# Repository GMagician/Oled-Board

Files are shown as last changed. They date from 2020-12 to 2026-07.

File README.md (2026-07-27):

>[!WARNING]
>The transfer of all repositories to my [Codeberg account](https://codeberg.org/GMagician) is currently ongoing. In the future, this project will be continued here!
# SDD1306 1.3" OLED Board

This board has been inspired by Leonerd it's an open source and open hardware.
On the hardware side is fully compatible (not tested with 5V input tolerant boards)
On software side there are some new features usefull for SMuFF device

**PLEASE NOTE REV1 HAS PCB ERRORS. TO PROPERLY WORK NEED SOME PCB, PINS, PADS AND ROUTES CUTTING. THESE SHOULD BE FIXED IN REV2 BRANCH**

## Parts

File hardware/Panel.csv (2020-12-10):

Id | Riferimento | Contenitore | Quantità | Valore | Produttore
1 | SW101 | RotaryEncoder_Alps_EC11E-Switch_Vertical_H20mm | 1 | Rotary Encoder + Switch
2 | U102 | SOP-20_7.5x12.8mm_P1.27mm | 1 | ATtiny4313
3 | J203 | OLED-128O064D | 1 | SSD1306
4 | R204 | R_0805_2012Metric_Pad1.20x1.40mm_HandSolder | 1 | 910K
5 | R203,R202,R201,R103,R102 | R_0805_2012Metric_Pad1.20x1.40mm_HandSolder | 5 | 4K7
6 | R105 | R_0805_2012Metric_Pad1.20x1.40mm_HandSolder | 1 | 180
7 | R104 | R_0805_2012Metric_Pad1.20x1.40mm_HandSolder | 1 | 330
8 | R101 | R_0805_2012Metric_Pad1.20x1.40mm_HandSolder | 1 | 560
9 | D201 | D_SOD-323 | 1 | 1N4148WS
10 | C207 | C_0805_2012Metric_Pad1.18x1.45mm_HandSolder | 1 | 10µF
11 | C206 | C_0805_2012Metric_Pad1.18x1.45mm_HandSolder | 1 | 2.2µF/16V
12 | C205,C104,C103,C102 | C_0805_2012Metric_Pad1.18x1.45mm_HandSolder | 4 | 0.1µF
13 | C204,C203,C202,C201,C101 | C_0805_2012Metric_Pad1.18x1.45mm_HandSolder | 5 | 1µF
14 | U101 | SOT-23 | 1 | XC6206P
15 | Q101 | SOT-23 | 1 | 2N7002
16 | J202 | PinHeader_1x02_P2.54mm_Vertical | 1 | Conn_01x02
17 | J201 | PinHeader_1x02_P2.54mm_Vertical | 1 | Power supply
18 | J104,J101 | PinSocket_1x02_P2.54mm_Vertical | 2 | Conn_01x02
19 | BZ101 | PUIAudio_SMT_0825_S_4_R | 1 | Buzzer
20 | SW104 | B3W-9000-RG2 | 1 | B3W-9000-RG2N
21 | SW103,SW102 | SW_SPST_Omron_B3FS-100xP | 2 | 10mm
22 | J103 | PinHeader_2x03_P2.54mm_Vertical | 1 | Header
23 | J102 | JST_XH_B6B-XH-A_1x06_P2.50mm_Vertical | 1 | Header

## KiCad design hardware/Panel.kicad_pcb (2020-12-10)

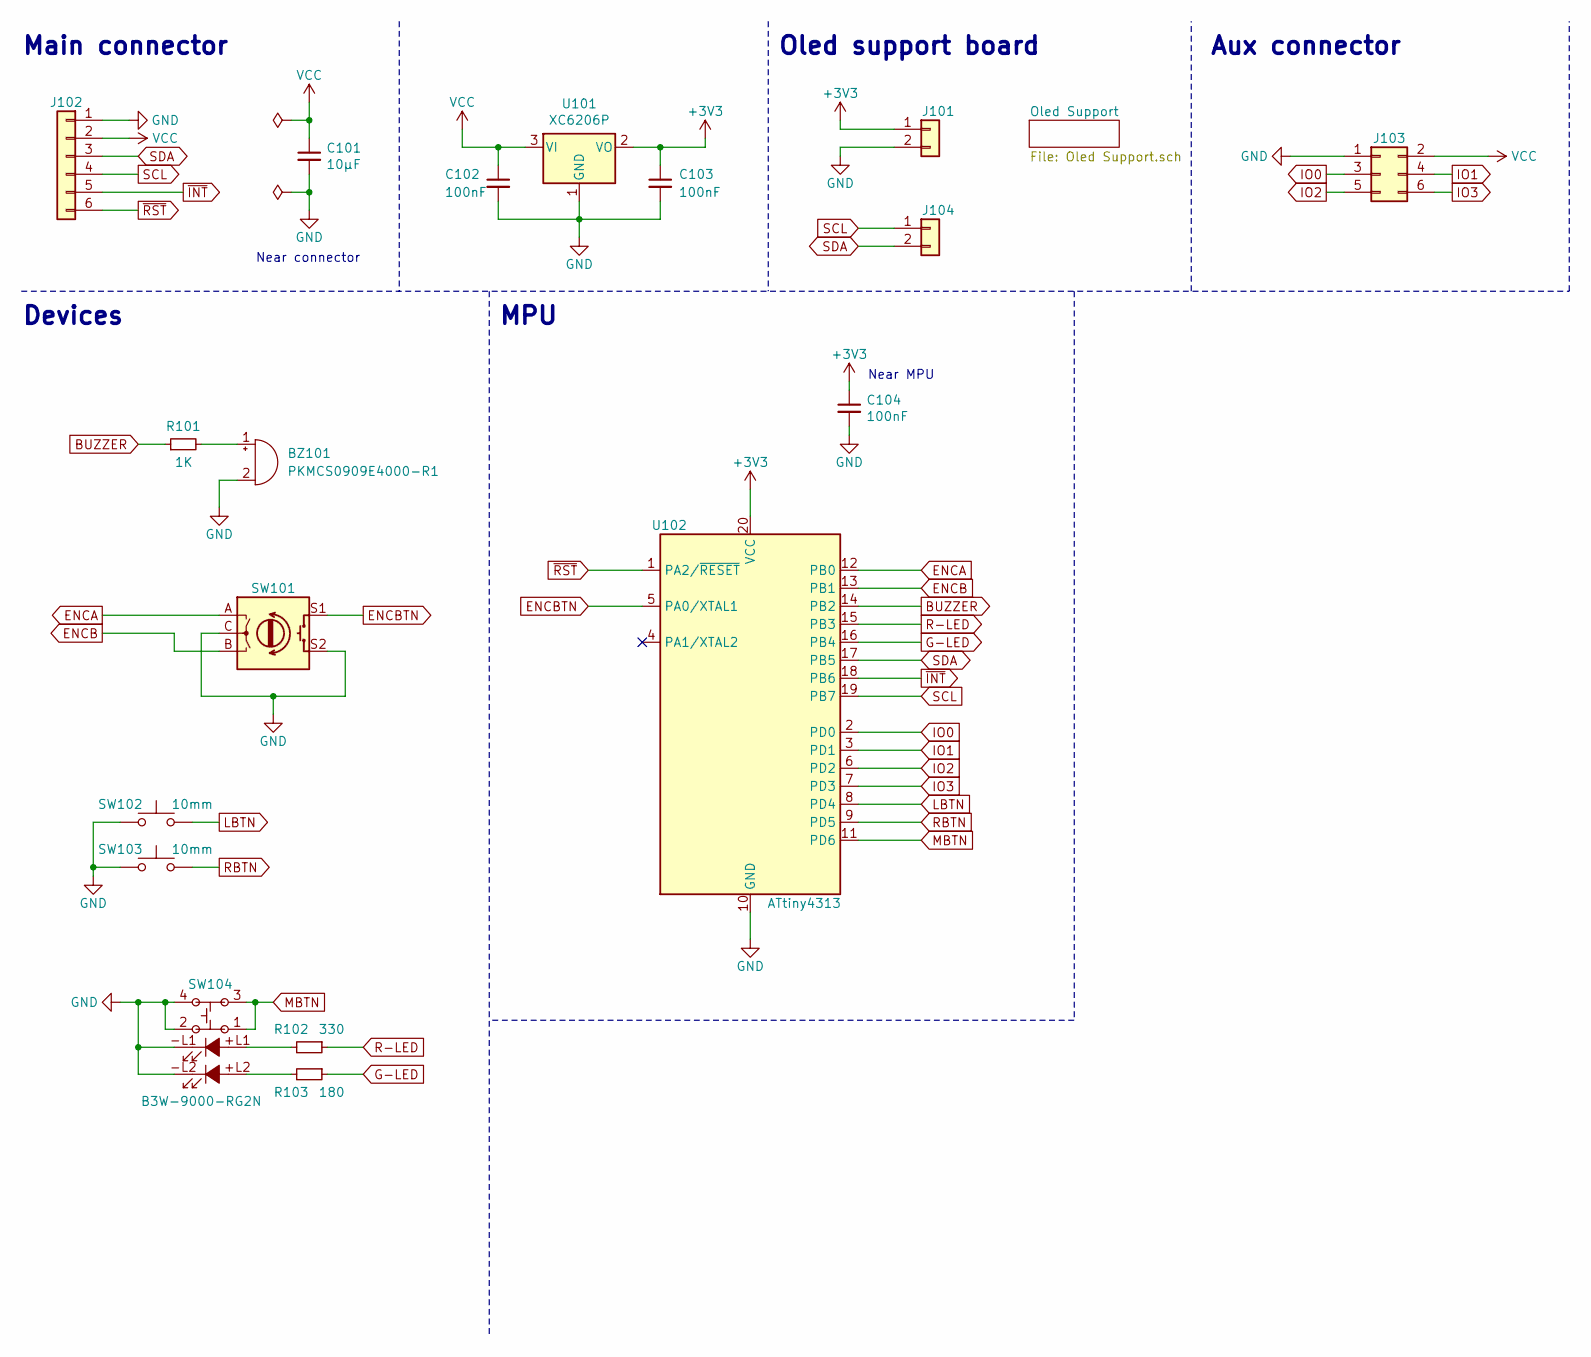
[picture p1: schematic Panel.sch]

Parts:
BZ101: PKMCS0909E4000-R1; Buzzer_Murata_PKMCS0909E4000-R1
C101: 10µF; C_0805_2012Metric_Pad1.18x1.45mm_HandSolder; LCSC C15850
C102, C103, C104: 100nF; C_0805_2012Metric_Pad1.18x1.45mm_HandSolder; LCSC C49678
J101, J104: Conn_01x02; OledSupport-header
J102: Header; JST_XH_B6B-XH-A_1x06_P2.50mm_Vertical
J103: Header; PinHeader_2x03_P2.54mm_Vertical
R101: 1K; R_0805_2012Metric_Pad1.20x1.40mm_HandSolder; LCSC C17513
R102: 330; R_0805_2012Metric_Pad1.20x1.40mm_HandSolder; LCSC C17630
R103: 180; R_0805_2012Metric_Pad1.20x1.40mm_HandSolder; LCSC C25270
SW101: Rotary Encoder + Switch; RotaryEncoder_Alps_EC11E-Switch_Vertical_H20mm
SW102, SW103: 10mm; SW_SPST_Omron_B3FS-100xP
SW104: B3W-9000-RG2N; B3W-9000-RG2
U101: XC6206P; SOT-23; LCSC C5446
U102: ATtiny4313; SOIC-20W_7.5x12.8mm_P1.27mm; LCSC C72467

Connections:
+3V3: C103.1, C104.1, J101.1, U101.2 (VO), U102.20 (VCC); also elsewhere on the board
BUZZER: R101.1, U102.14 (PB2)
ENCA: SW101.A, U102.12 (PB0)
ENCB: SW101.B, U102.13 (PB1)
ENCBTN: SW101.S1, U102.5 (PA0/XTAL1)
G-LED: R103.1, U102.16 (PB4)
GND: BZ101.2 (+), C101.2, C102.2, C103.2, C104.2, J101.2, J102.1, J103.1, SW101.C, SW101.S2, SW102.1, SW103.1, SW104.2, SW104.4, SW104.-L1, SW104.-L2, U101.1 (GND), U102.10 (GND); also elsewhere on the board
IO0: J103.3, U102.2 (PD0)
IO1: J103.4, U102.3 (PD1)
IO2: J103.5, U102.6 (PD2)
IO3: J103.6, U102.7 (PD3)
LBTN: SW102.2, U102.8 (PD4)
MBTN: SW104.1, SW104.3, U102.11 (PD6)
unnamed: BZ101.1 (-), R101.2
unnamed: R102.2, SW104.+L1
unnamed: R103.2, SW104.+L2
R-LED: R102.1, U102.15 (PB3)
RBTN: SW103.2, U102.9 (PD5)
SCL: J102.4, J104.1, U102.19 (PB7); also elsewhere on the board
SDA: J102.3, J104.2, U102.17 (PB5); also elsewhere on the board
VCC: C101.1, C102.1, J102.2, J103.2, U101.3 (VI)
~INT: J102.5, U102.18 (PB6)
~RST: J102.6, U102.1 (PA2/~RESET)

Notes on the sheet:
Main connector
Devices
Oled support board
Near connector
MPU
Near MPU
Aux connector

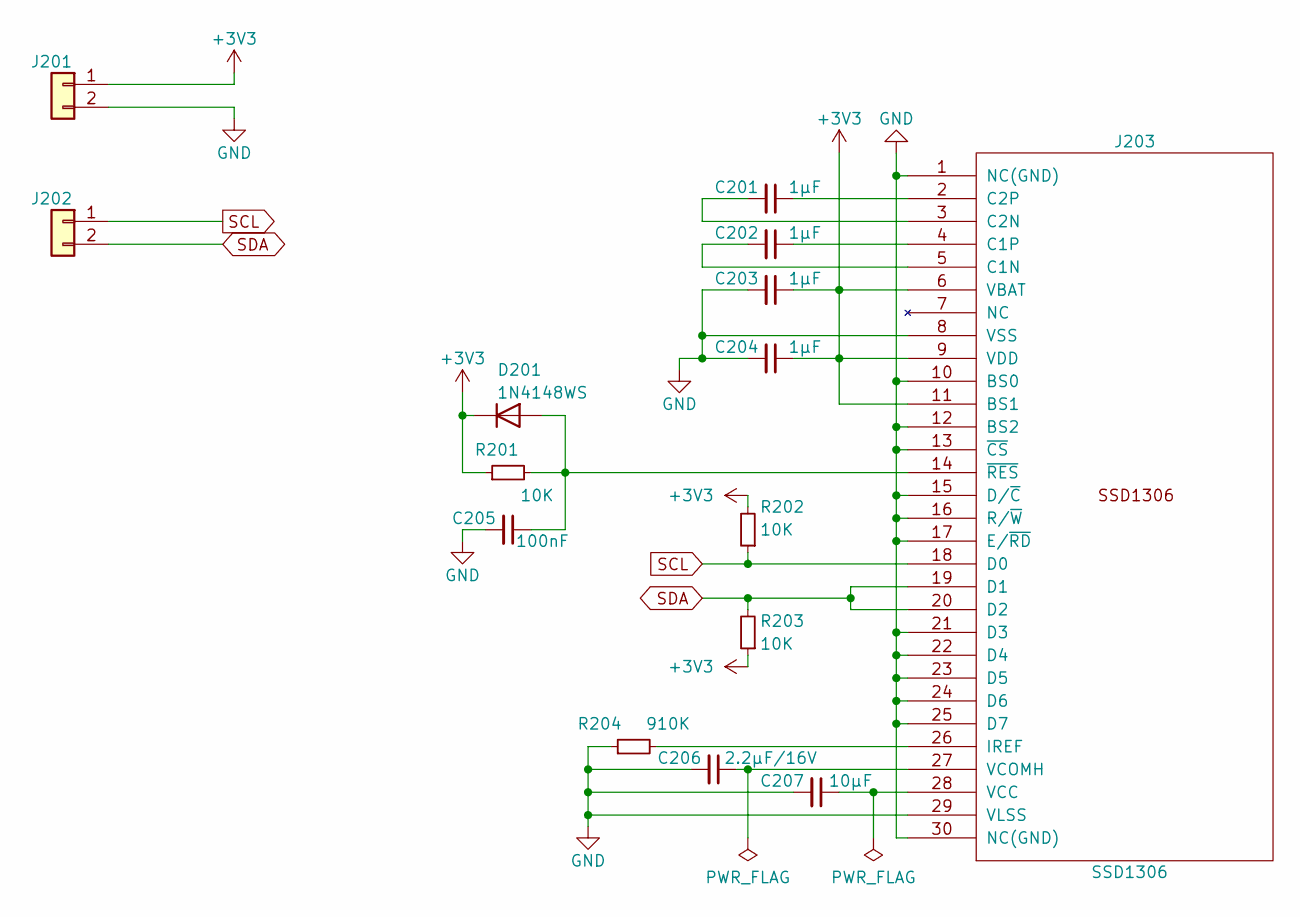
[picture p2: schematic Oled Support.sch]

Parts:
C201, C202, C203, C204: 1µF; C_0805_2012Metric_Pad1.18x1.45mm_HandSolder; LCSC C28323
C205: 100nF; C_0805_2012Metric_Pad1.18x1.45mm_HandSolder; LCSC C49678
C206: 2.2µF/16V; C_0805_2012Metric_Pad1.18x1.45mm_HandSolder; LCSC C49217
C207: 10µF; C_0805_2012Metric_Pad1.18x1.45mm_HandSolder; LCSC C15850
D201: 1N4148WS; D_SOD-323; LCSC C2128
J201, J202: Conn_01x02; PinHeader_1x02_P2.54mm_Vertical
J203: SSD1306; OLED-128O064D
R201, R202, R203: 10K; R_0805_2012Metric_Pad1.20x1.40mm_HandSolder; LCSC C17414
R204: 910K; R_0805_2012Metric_Pad1.20x1.40mm_HandSolder; LCSC C17864

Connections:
+3V3: C203.1, C204.1, D201.1 (K), J201.1, J203.6 (VBAT), J203.9 (VDD), J203.11 (BS1), R201.1, R202.2, R203.1; also elsewhere on the board
GND: C203.2, C204.2, C205.2, C206.2, C207.2, J201.2, J203.1 (NC(GND)), J203.8 (VSS), J203.10 (BS0), J203.12 (BS2), J203.13 (~CS), J203.15 (D/~C), J203.16 (R/~W), J203.17 (E/~RD), J203.21 (D3), J203.22 (D4), J203.23 (D5), J203.24 (D6), J203.25 (D7), J203.29 (VLSS), J203.30 (NC(GND)), R204.1; also elsewhere on the board
unnamed: C201.1, J203.2 (C2P)
unnamed: C201.2, J203.3 (C2N)
unnamed: C202.1, J203.4 (C1P)
unnamed: C202.2, J203.5 (C1N)
unnamed: C205.1, D201.2 (A), J203.14 (~RES), R201.2
unnamed: C206.1, J203.27 (VCOMH)
unnamed: C207.1, J203.28 (VCC)
unnamed: J203.26 (IREF), R204.2
SCL: J202.1, J203.18 (D0), R202.1; also elsewhere on the board
SDA: J202.2, J203.19 (D1), J203.20 (D2), R203.2; also elsewhere on the board

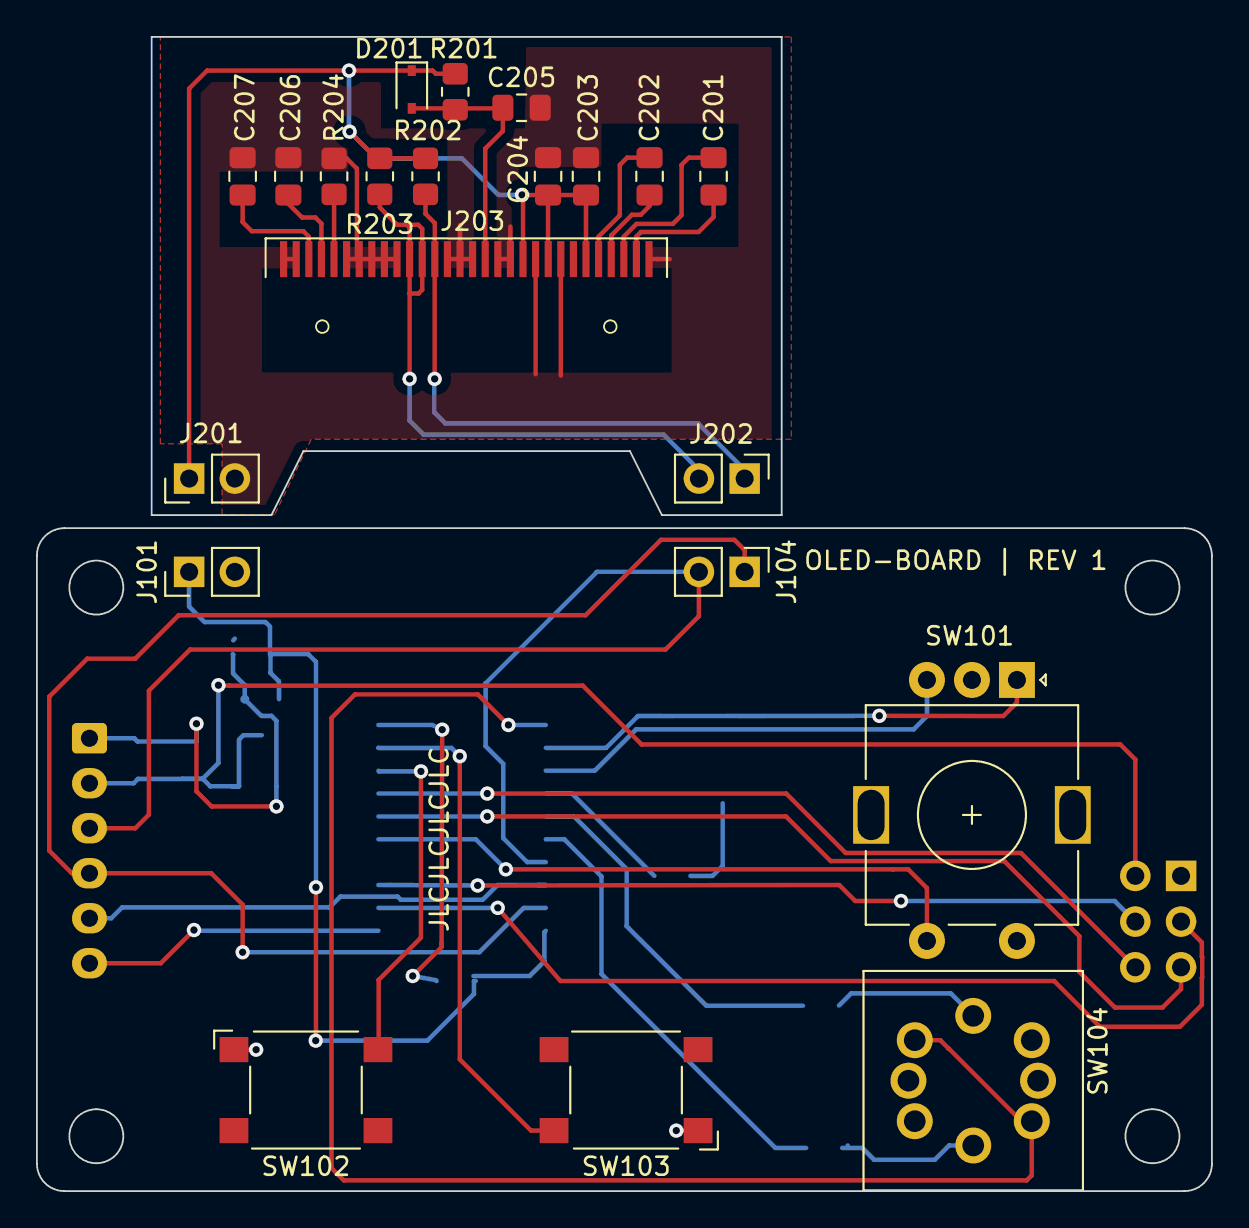
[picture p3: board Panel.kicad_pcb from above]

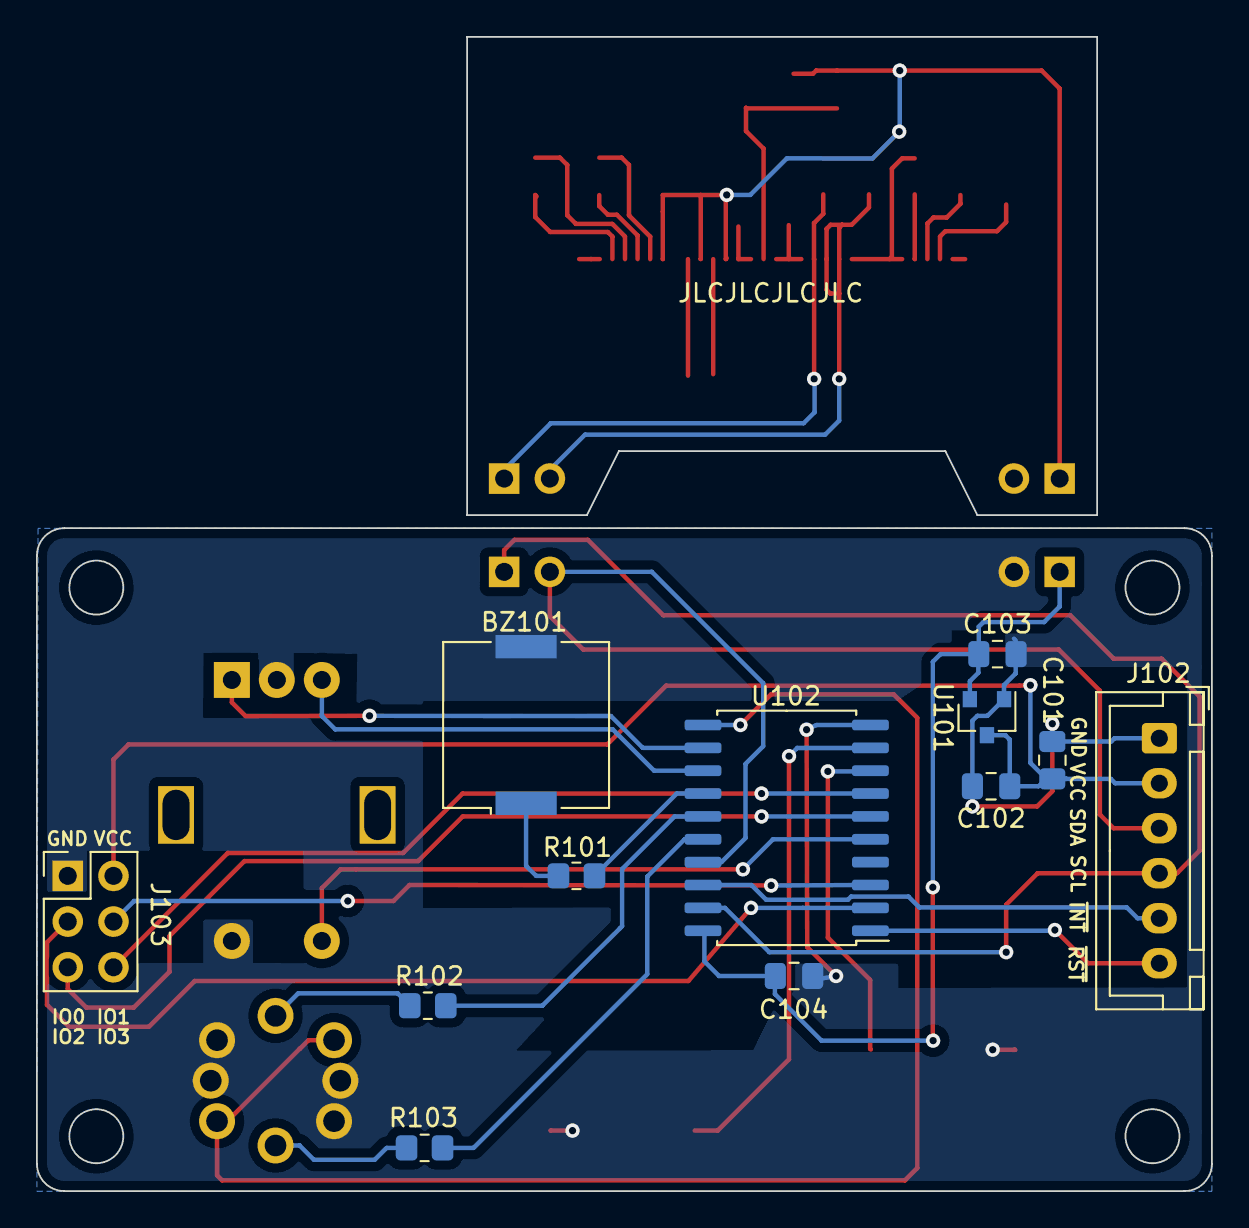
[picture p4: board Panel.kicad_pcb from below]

Board: 2 copper layers, 65.3 x 64.1 mm, 33 parts (12 on the bottom side), 31 nets.

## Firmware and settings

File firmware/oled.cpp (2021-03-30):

/**
 * Oled 1.3" control board
 *
 * Copyright(C) 2020-2021 GMagician
 *
 * Part of this code is extracted from framework source and modified to reduce footprint
 */
#include "include/oled.h"

static I2CRegister i2cRegister;

static const Configuration PROGMEM defaultConfig = {
  .i2cAddress = 0x3D,
  .option = { .wheelAcceleration = false, .reverseEncoder = false },
  .buttonsDebounceTime = 20,
  .buttonsHoldTime = 75,
  .buttonsRemapMask = 0b0000,
  .buttonsRemapPolarity = 0b0000,
  .encoderAccRate = 25,
  .encoderDecRate = 2
};
static Configuration config;

static uint8_t gpioDirMask,
               gpioPullUpMask,
               gpioEventMask,
               gpioOutStatusMask;

static uint16_t beepFrequency = 2000;

static uint8_t redLedDuty,
               greenLedDuty;

static uint8_t buttonsReleaseMask,
               keyBeepMask,
               keyBeepDuration = 10;      // centiseconds

static uint16_t toneUsedFrequency;

static bool wheelHasMoved;
static int16_t wheelAccComponent;

#define QUEUE_SIZE    8   // MUST BE x^2
static Event eventsQueue[QUEUE_SIZE];
static volatile uint8_t eventsCount,
                        eventsHeadIndex,
                        eventsTailIndex;


/******************************/
/* WHEEL ACCELERATION HANDLER */
/******************************/
void wheelAccelerationHandler() {
  if (wheelHasMoved) {
    wheelHasMoved = false;
    wheelAccComponent += config.encoderAccRate;
    if (wheelAccComponent > (7 << 8))
      wheelAccComponent = (7 << 8);
  }
  else {
    wheelAccComponent -= config.encoderDecRate;
    if (wheelAccComponent < 0)
      wheelAccComponent = 0;
  }
}


/****************************/
/* BASE TIME TIMER HANDLING */
/****************************/
#define ms_TIMER_PRESCALER  0b010                                 // clk/8 (PWM=4KHz)
#define uS_X_ms_OVERFLOW    (clockCyclesToMicroseconds(8 * 256))  // 8=prescaler
#define FRACT_INC           ((uS_X_ms_OVERFLOW % 1000) >> 3)
#define FRACT_MAX           (1000 >> 3)

static uint16_t timerMillisCount;
static uint8_t timerFractionalCount;

SIGNAL(TIMER1_OVF_vect) {
  // copy to local variables so it can be stored in registers and shrink code
  uint8_t f = timerFractionalCount;

  f += FRACT_INC;
  if (f >= FRACT_MAX) {
    f -= FRACT_MAX;
    ++timerMillisCount;

    if (config.option.wheelAcceleration)
      wheelAccelerationHandler();
  }

  timerFractionalCount = f;
}

uint16_t millis() {
  uint16_t m;

  // timerMillisCount read is not atomic then disable interrupts to prevent race conditions
  uint8_t savedSREG = SREG;
  noInterrupts();
  m = timerMillisCount;
  SREG = savedSREG;

  return m;
}


/*******************/
/* EEPROM HANDLING */
/*******************/
/**
 *  Load value from eeprom specified address
 */
uint8_t eeRead(uint8_t address) {
  // Wait eeprom idle
  while(EECR & _BV(EEPE))
    ;
  EEAR = address;
  sbi (EECR, EERE);

  return EEDR;
}

/**
 *  Save value into eeprom at specified address
 */
void eeWrite(uint8_t address, uint8_t value) {
  // Wait eeprom idle
  while(EECR & _BV(EEPE))
    ;
  // Set Programming mode
  EECR &= ~(_BV(EEPM1) | _BV(EEPM0));
  // Set up address and data
  EEAR = address;
  EEDR = value;

  uint8_t savedSREG = SREG;
  noInterrupts();
  sbi(EECR, EEMPE);   // Program enable
  sbi(EECR, EEPE);    // Start write
  SREG = savedSREG;
}

/**
 *  Load configuration from eeprom
 */
void loadConfiguration() {
  uint8_t * configPtr = (uint8_t *)&config;
  for (uint8_t eeAddr = 0; eeAddr < sizeof(config); ++eeAddr, ++configPtr)
    *configPtr = eeRead(eeAddr);

  if (config.i2cAddress & 0b10000000) {
    // Most important thing is i2c address.
    // If invalid restore eeprom defaults to let user to communicate
    uint8_t * configPtr = (uint8_t *)&config;
    const uint8_t * defConfigPtr = (const uint8_t *)&defaultConfig;
    for (uint8_t eeAddr = 0; eeAddr < sizeof(config); ++eeAddr, ++configPtr, ++defConfigPtr) {
      *configPtr = pgm_read_byte(defConfigPtr);
      eeWrite(eeAddr, *configPtr);
    }
  }
}


/**************/
/* BOARD CODE */
/**************/
/**
 *  Signal interrupt event
 */
FORCE_INLINE void setInterruptPin() {
  OUT_WRITE(INTERRUPT_PIN, LOW);
}

/**
 *  Clear interrupt event
 */
FORCE_INLINE void resetInterruptPin() {
  SET_INPUT_PULLUP(INTERRUPT_PIN);
}

/**
 *  Read GPIOs
 */
FORCE_INLINE uint8_t readGPIOs() {
  #if GPIO3_PIN == PD3 && GPIO2_PIN == PD2 && GPIO1_PIN == PD1 && GPIO0_PIN == PD0
    return PIND & 0x0F;
  #else
    return (READ(GPIO3_PIN) << 3) | (READ(GPIO2_PIN) << 2) | (READ(GPIO1_PIN) << 1) | READ(GPIO0_PIN);
  #endif
}

/**
 *  Set red led brightness
 */
void setRedLEDBrightness() {
  SET_LEDSPWM_DUTY(REDLED_PIN, redLedDuty);
}

/**
 *  Set green led brightness
 */
void setGreenLEDBrightness() {
  SET_LEDSPWM_DUTY(GREENLED_PIN, greenLedDuty);
}

/**
 *  Add an event into queue
 */
void pushEvent(Event event) {
  if (eventsCount == QUEUE_SIZE) return;

  eventsQueue[eventsHeadIndex] = event;
  eventsHeadIndex = (eventsHeadIndex + 1) & (QUEUE_SIZE - 1);
  uint8_t savedSREG = SREG;
  noInterrupts();
  ++eventsCount;
  setInterruptPin();
  SREG = savedSREG;
}

/**
 *  Extract an event from queue
 */
Event popEvent() {
  if (eventsCount == 0)
    return NO_EVENT;

  Event event = eventsQueue[eventsTailIndex];
  if (--eventsCount == 0)
    resetInterruptPin();
  eventsTailIndex = (eventsTailIndex + 1) & (QUEUE_SIZE - 1);

  return event;
}

/**
 *  Play a tone of the specified duration
 */
static uint32_t toneTimerToggleCount;

ISR(TIMER0_COMPA_vect) {
  --toneTimerToggleCount;
  if (toneTimerToggleCount == 0) {
    cbi(TIMSK, OCIE0A);                               // Disable interrupt
    TCCR0B = 0b00000000;                              // Stop the clock (only some CS0x bits may be set so no matter if I write 0)
    WRITE(BUZZER_PIN, LOW);                           // Mute buzzer
  }
}

void playTone(uint8_t centisecs) {
  if (centisecs == 0 || beepFrequency == 0)
    return;

  toneUsedFrequency = beepFrequency;

  if (!(TIMSK & _BV(OCIE0A))) {
    TCNT0 = 0;            // Start timer at 0
    sbi(TIFR, OCF0A);     // Clear the Timer interrupt flag
  }

  // Determine which prescaler to use
  // Set the Output Compare Register (rounding up)
  uint32_t ocr = F_CPU / 2 / beepFrequency;
  uint8_t prescalerBits = 0b001;  // clk/1
  if (ocr > 256) {
    ocr >>= 3;
    prescalerBits = 0b010;        // clk/8
    if (ocr > 256) {
      ocr >>= 3;
      prescalerBits = 0b011;      // clk/64
      if (ocr > 256) {
        ocr >>= 2;
        prescalerBits = 0b100;    // clk/256
        if (ocr > 256) {
          // Can't do any better
          ocr >>= 2;
          prescalerBits = 0b101;  // clk/1024
        }
      }
    }
  }
  ocr -= 1; // Note we are doing the subtraction of 1 here to save repeatedly calculating ocr from just the frequency in the if tree above
  OCR0A = ocr;

  // Determine how many times the value toggles
  toneTimerToggleCount = (2L * beepFrequency * centisecs) / 100;

  // Output Compare A Match Interrupt Enable
  sbi(TIMSK, OCIE0A);

  // Start timer
  TCCR0B = prescalerBits << CS00;   // No other bits but CS0x are modified in whole code
}

/**
 *  GPIO initialization
 */
void gpioSetup() {
  MREPEAT(NUM_OF_GPIO, GPIO_SETUP);
}


/****************/
/* I2C HANDLING */
/****************/
/**
 *  Handle I2C registers requests
 */
uint8_t i2cRegisterHandler(bool isWrite, uint8_t value = 0) {
  switch (i2cRegister) {
    case EVENT:
      return isWrite ? -1 : popEvent().rawData;

    case RELEASEMASK:
      if (isWrite)
        buttonsReleaseMask = value >> 1;  // Remove unused bit
      return buttonsReleaseMask << 1;     // Restore for unused bit

    case DEBOUNCE_TIME:
      if (isWrite)
        config.buttonsDebounceTime = value;
      return config.buttonsDebounceTime;

    case BTNHOLD_TIME:
      if (isWrite)
        config.buttonsHoldTime = value;
      return config.buttonsHoldTime;

    case KEYBEEP_DURATION:
      if (isWrite)
        keyBeepDuration = value;
      return keyBeepDuration;

    case KEYBEEP_MASK:
      if (isWrite)
        keyBeepMask = value;
      return keyBeepMask;

    case BEEP_DURATION:
      if (isWrite)
        playTone(value);
      return toneTimerToggleCount * 1000 / 2 / toneUsedFrequency;

    case BEEP_TONE:
      if (isWrite)
        beepFrequency = uint16_t(value) * 10;
      return beepFrequency / 10;

    case BEEP_FREQ_HIGH:
      if (isWrite)
        beepFrequency = (uint16_t(value) << 8) | (beepFrequency & 0xFF);
      return beepFrequency >> 8;

    case BEEP_FREQ_LOW:
      if (isWrite)
        beepFrequency = (beepFrequency & 0xFF00) | value;
      return beepFrequency;

    case REDLED_PWM:
      if (isWrite) {
        redLedDuty = value;
        setRedLEDBrightness();
      }
      return redLedDuty;

    case GREENLED_PWM:
      if (isWrite) {
        greenLedDuty = value;
        setGreenLEDBrightness();
      }
      return greenLedDuty;

    case GPIO_DIR:
      if (isWrite) {
        gpioDirMask = value;
        gpioSetup();
      }
      return gpioDirMask;

    case GPIO_IO:
      if (isWrite)
        gpioOutStatusMask = value;
      return readGPIOs();

    case GPIO_PULLUP:
      if (isWrite) {
        gpioPullUpMask = value;
        gpioSetup();
      }
      return gpioPullUpMask;

    case GPIO_EVENTMASK:
      if (isWrite)
        gpioEventMask = value & (_BV(NUM_OF_GPIO) - 1);
      return gpioEventMask;

    case SWVERSION:
      return 2;

    default:
      uint8_t eepromAddr = (i2cRegister - I2C_EEPROM);
      if (i2cRegister >= I2C_EEPROM && eepromAddr < sizeof(config)) {
        if (isWrite)
          eeWrite(eepromAddr, value);
        return eeRead(eepromAddr);
      }
      return 0xFF;
  }
}

/**
 *  i2c "received data" event handler
 */
void onI2CReceive(int availableData) {
  if (availableData) {
    i2cRegister = I2CRegister(USI_TWI_Receive_Byte());
    while (--availableData > 0) {
      i2cRegisterHandler(true, USI_TWI_Receive_Byte());
      ++i2cRegister;
    }
  }
}

/**
 *  I2C "to transmit data" event handler
 */
void onI2CRequest() {
  int8_t value = i2cRegisterHandler(false);
  USI_TWI_Transmit_Byte(value);
}


/**************************/
/* FRAMEWORK ENTRY POINTS */
/**************************/
/**
 *  Hardware initializations
 */
void setup() {
  noInterrupts();
  CLKPR = _BV(CLKPCE);      // System clock divisor to 1 (clock is 8MHz)
  CLKPR = 0b00000000;
  interrupts();

  // Timer 1 in Fast PWM mode (Clear Timer on 0xFF, disconnect OC1A)
  TCCR1A = _BV(WGM10);
  TCCR1B = _BV(WGM12) | (ms_TIMER_PRESCALER << CS10);
  TIMSK = _BV(TOIE1);

  // Main button
  SET_INPUT_PULLUP(MAINBTN_PIN);
  SET_PWM(REDLED_PIN);
  setRedLEDBrightness();
  SET_PWM(GREENLED_PIN);
  setGreenLEDBrightness();

  // Buttons
  SET_INPUT_PULLUP(LEFTBTN_PIN);
  SET_INPUT_PULLUP(RIGHTBTN_PIN);

  // Encoder
  SET_INPUT_PULLUP(ENCA_PIN);
  SET_INPUT_PULLUP(ENCB_PIN);
  SET_INPUT_PULLUP(ENCBTN_PIN);

  // Buzzer
  TCCR0B = 0b00000000;                              // Reset to default (it's initialized by framework init code)
  TCCR0A = (COM_TOGGLE << COM0A0) | _BV(WGM01);     // Timer in CTC mode (Clear Timer on OCR0A, toggle OC0A on Compare Match)
  OUT_WRITE(BUZZER_PIN, LOW);
  toneUsedFrequency = beepFrequency;                // Initialize if read before playing a tone

  loadConfiguration();     // Read EEPROM stored configuration

  // GPIO
  gpioSetup();

  // Interrupt pin
  resetInterruptPin();

  // I2C
  USI_TWI_Slave_Initialise(config.i2cAddress);
  USI_TWI_On_Slave_Receive = onI2CReceive;
  USI_TWI_On_Slave_Transmit = onI2CRequest;

  // Floating pins are not a good thing, pull'em up
  SET_INPUT_PULLUP(UNUSED1_PIN);
}

/**
 *  Main loop
 */
void loop() {
  uint16_t actualTime = millis();

  //  Buttons handling
  static uint8_t debouncedButtonsStatus,
                 buttonsHeldStatus;
  static uint16_t pressTime[RIGHT+1];     // +1 is required to have a good sized array

  uint8_t buttonsStatus = (!READ(RIGHTBTN_PIN) << RIGHT) |
                          (!READ(LEFTBTN_PIN) << LEFT) |
                          (!READ(MAINBTN_PIN) << MAIN) |
                          (!READ(ENCBTN_PIN) << WHEEL);
  for (ButtonID btnID = WHEEL; btnID <= RIGHT; ++btnID) {
    uint8_t btnMask = _BV(btnID);

    if (buttonsStatus & btnMask) {
      // Debounce
      if (!(debouncedButtonsStatus & btnMask) && (actualTime - pressTime[btnID]) >= config.buttonsDebounceTime) {
        debouncedButtonsStatus |= btnMask;

        Event event = BUTTON_EVENT(PRESS, btnID);
        pushEvent(event);

        if ((keyBeepMask >> 1) & btnMask) // keyBeepMask bit 0 is wheel movement so >> 1 to get only buttons
          playTone(keyBeepDuration);
      }
      // Held detection
      if (!(buttonsHeldStatus & btnMask) && (actualTime - pressTime[btnID]) >= (config.buttonsHoldTime * 10)) {
        buttonsHeldStatus |= btnMask;

        Event event = BUTTON_EVENT(HELD, btnID);
        pushEvent(event);
      }
    }
    else /*if (!(buttonsStatus & btnMask))*/ {
      // Button has been release, check if event is required
      if (debouncedButtonsStatus & buttonsReleaseMask & btnMask) {
        Event event = BUTTON_EVENT(RELEASE, btnID);
        pushEvent(event);
      }
      debouncedButtonsStatus &= ~btnMask;
      buttonsHeldStatus &= ~btnMask;
      pressTime[btnID] = actualTime;
    }
  }

  // Rotary encoder handling (with acceleration)
  static bool triggerArmed,
              prevEncA,
              prevEncB;

  bool encA = READ(ENCA_PIN);
  bool encB = READ(ENCB_PIN);
  bool encBChanged = encB ^ prevEncB;
  wheelHasMoved |= (encA ^ prevEncA || encBChanged);
  if (prevEncA)
    triggerArmed = prevEncA;
  else if (triggerArmed) {
    if (encBChanged) {
      bool cw = prevEncB ^ config.option.reverseEncoder;
      Event event = ENCODER_EVENT(cw);
      pushEvent(event);

      if (keyBeepMask & 0b00001)
        playTone(keyBeepDuration);

      triggerArmed = false;
    }
  }
  prevEncB = encB;
  prevEncA = encA;

  // GPIO handling
  static uint8_t prevGPIOStatus;

  uint8_t gpioStatus = readGPIOs();
  if ((gpioStatus ^ prevGPIOStatus) & gpioEventMask) {
    Event event = GPIO_EVENT(gpioStatus);
    pushEvent(event);
  }
  prevGPIOStatus = gpioStatus;

  MREPEAT(NUM_OF_GPIO, GPIO_WRITE); // Always refresh outputs (needed when buttons are remapped to GPIOs)
}

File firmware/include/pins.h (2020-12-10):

#pragma once

#define ENCBTN_PIN            PA0
#define UNUSED1_PIN           PA1
//#define RESET_PIN           PA2

#define ENCA_PIN              PB0
#define ENCB_PIN              PB1
#define BUZZER_PIN            PB2
#define REDLED_PIN            PB3
#define GREENLED_PIN          PB4
//#define SDA_PIN             PB5
#define INTERRUPT_PIN         PB6
//#define SCL_PIN             PB7

#define GPIO0_PIN             PD0
#define GPIO1_PIN             PD1
#define GPIO2_PIN             PD2
#define GPIO3_PIN             PD3
#define LEFTBTN_PIN           PD4
#define RIGHTBTN_PIN          PD5
#define MAINBTN_PIN           PD6

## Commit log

2021-01-01 Fix eeprom default programming
    [oled.cpp]
2021-02-08 Report PCB issues
2021-02-20 Add PCB cut to warnings
    Oled pins are too far from edge and requires a PCB cut (sand) to be soldered
2021-03-30 Fixed wheel direction event
    Now event report proper cw/ccw action
    [oled.cpp]
